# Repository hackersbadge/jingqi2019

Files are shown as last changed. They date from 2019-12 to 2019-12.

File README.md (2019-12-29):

# Hacker's Badge for JD's JingQi 2019, Beijing

- [x] Hardware: WhiteA10n3
- [x] Code: chenhuitao/xwings

* SoC: MTK7688
* 1 x Antenna 
* WiFi Capable
* Breed Bootloader
* 2 Buttons
* 3 x LED

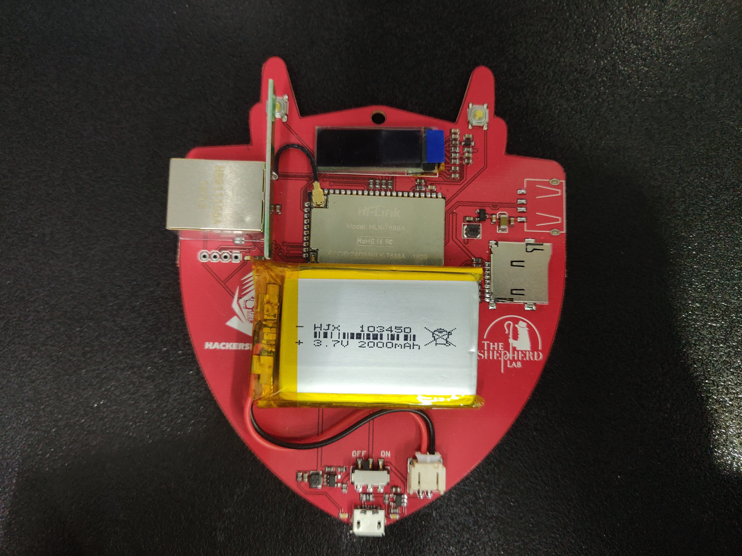
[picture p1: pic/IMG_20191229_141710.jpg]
badge0
      
badge0      
badge0

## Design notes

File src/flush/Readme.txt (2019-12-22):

1. 准备一台linux系统pc机，建议安装ubuntu。
2. 安装python3和curl。
3. 准备一台傻瓜交换机，接入两个网线。
4. 一根网线接入pc机，建议将pc机网络地址设置为192.168.1.100/24。
5. 打开终端，运行python breed_abort.py，此程序将不停在交换机局域网内广播breed abort的指令。
6. 再打开另一个终端，运行while [ true ]; do bash flush.sh; done，此程序会不停的检测breed的web server。
7. 另一根网线接入准备要刷入固件的机器。
8. 电源接入要刷入固件的机器并开启。
9. 观察网络灯是否有闪烁并持续一定时间，闪烁表示正在上传固件。
10. 固件刷入完成后，刷好的机器会自动重启。
11. 此时pc机的flush脚本检测到后会蜂鸣，pc机上的终端也会有提示。
12. 听到蜂鸣后或看到提示后，请在5秒内拔出已经刷机完成的网线，并拔出电源线。
13. 更换新的要刷入的机器，并跳回步骤7进行重复操作。

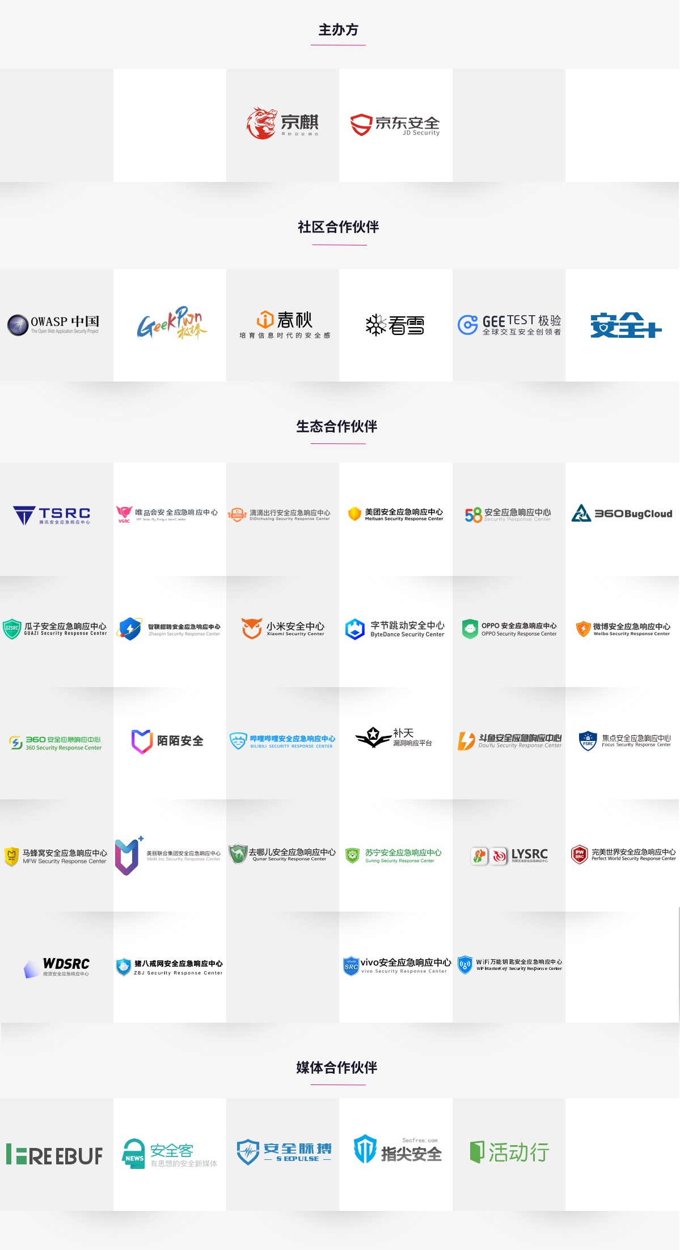
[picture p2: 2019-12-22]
src/package/utils/jd-jingqi/files/www/res/partner-pc.jpeg

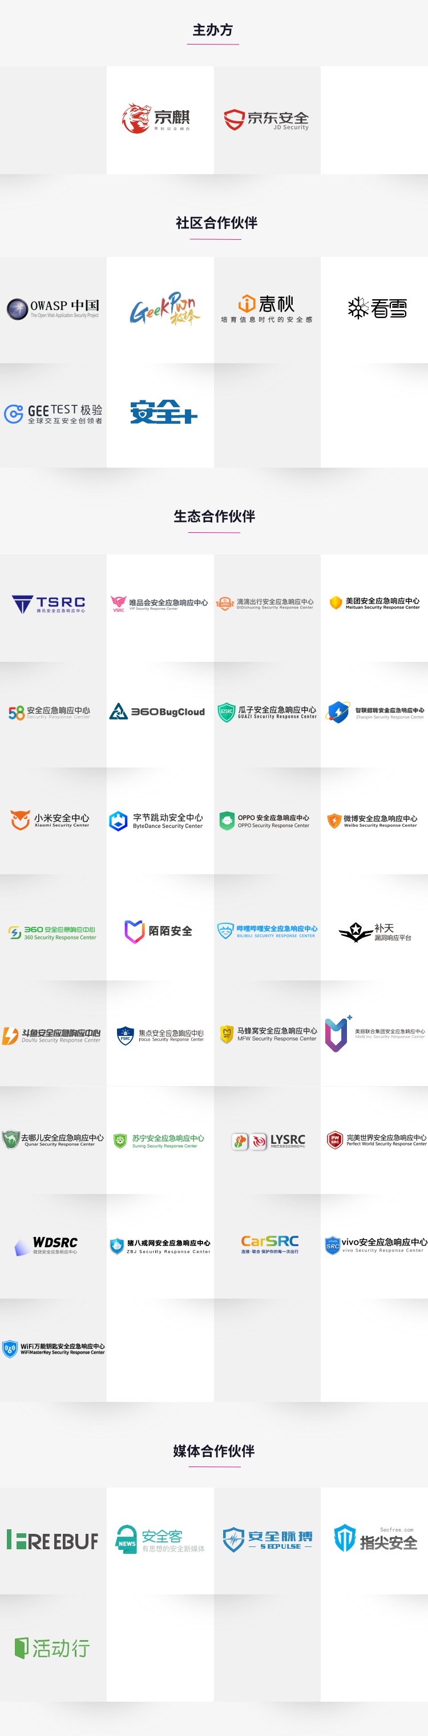
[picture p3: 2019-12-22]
src/package/utils/jd-jingqi/files/www/res/partner-mob.jpeg

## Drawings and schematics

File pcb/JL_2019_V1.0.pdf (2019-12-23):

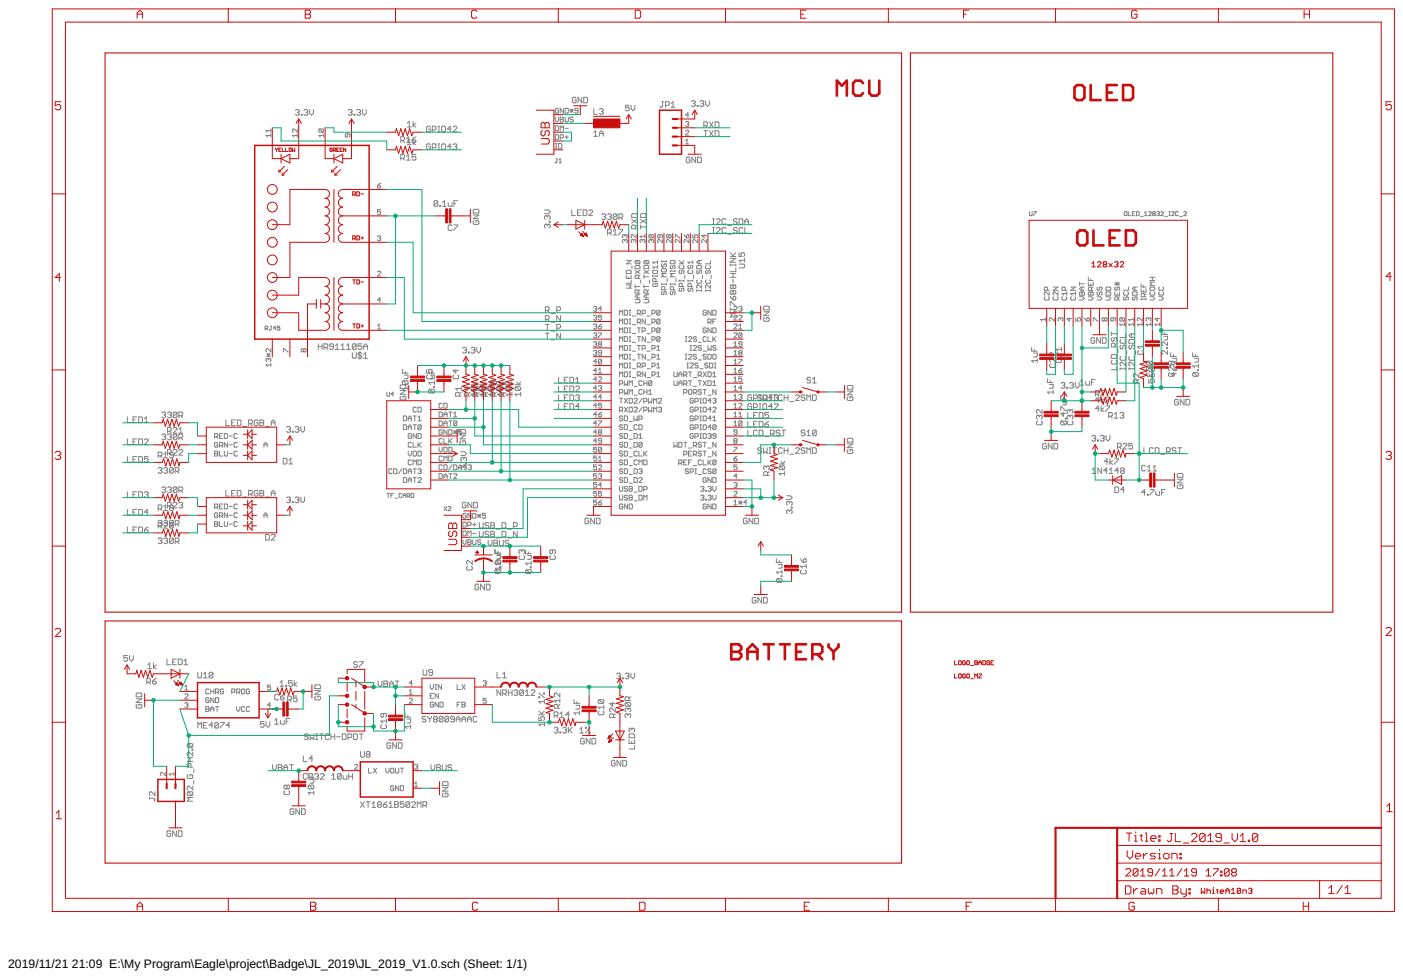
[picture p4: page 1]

2019/11/21 21:09 E:\My Program\Eagle\project\Badge\JL_2019\JL_2019_V1.0.sch (Sheet: 1/1)

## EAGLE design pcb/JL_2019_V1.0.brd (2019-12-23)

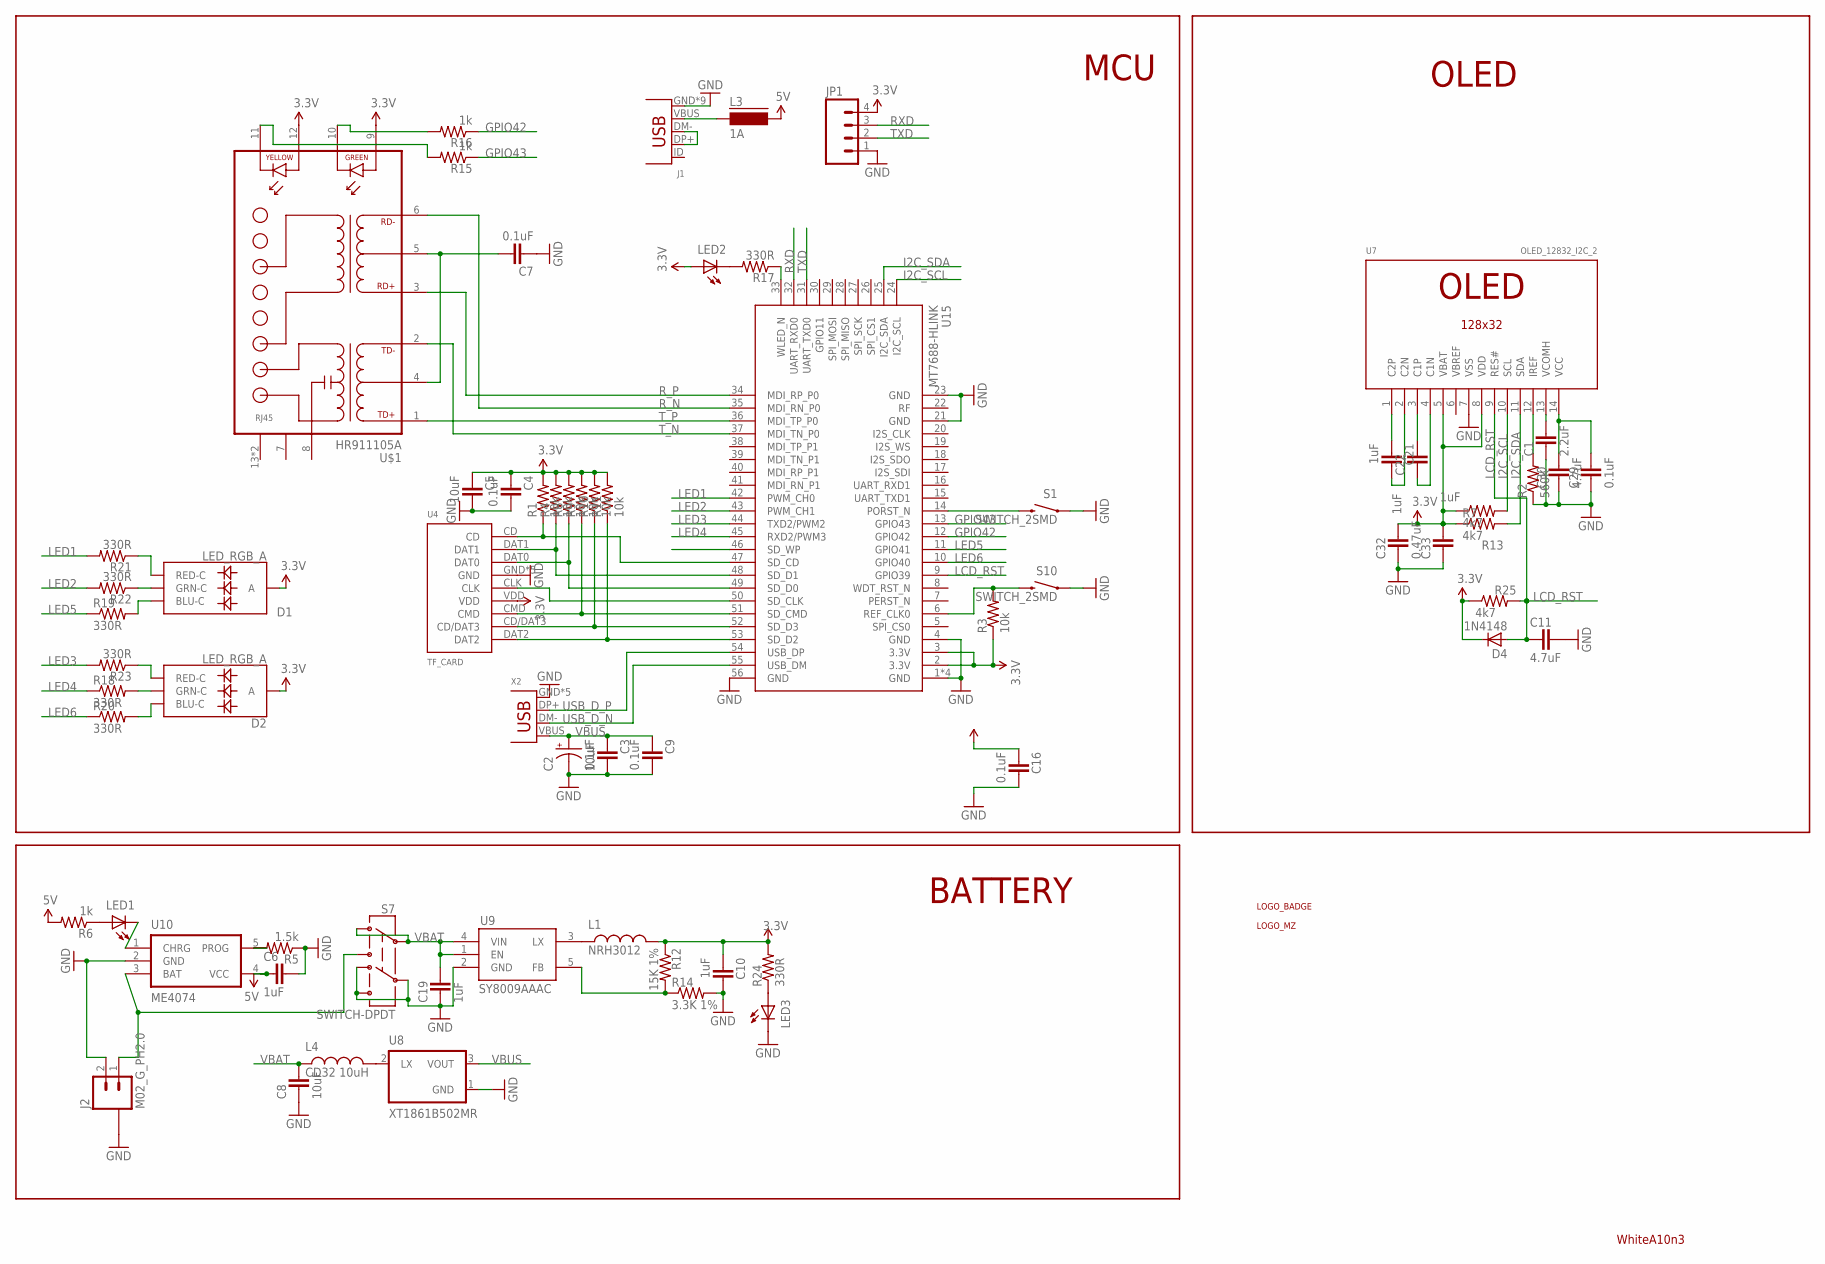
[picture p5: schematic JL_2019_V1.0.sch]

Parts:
C1: 2.2uF; 0603-CAP
C2: 10uF; EIA3216
C3, C4, C7, C9, C16, C29: 0.1uF; 0603-CAP
C5, C8: 10uF; 0603-CAP
C6, C10, C19, C21, C22, C33: 1uF; 0603-CAP
C11, C30: 4.7uF; 0603-CAP
C32: 0.47uF; 0603-CAP
D1, D2: LED_RGB_A; RGB-1615-A
D4: 1N4148; SOD-323F
J1: USB_5_MICRO_4; USB-MICRO-4
J2: M02_G_PH2.0; PH2.0_SMD_2
JP1: M04PTH; 1X04
L1: NRH3012; 1210
L3: 1A; FB805
L4: CD32 10uH; CD32
LED1, LED2, LED3: LED0603; LED-0603
R1, R3, R4, R8, R9, R10, R11: 10k; 0603-RES
R2: 560K; 0603-RES
R5: 1.5k; 0603-RES
R6, R15, R16: 1k; 0603-RES
R7, R13, R25: 4k7; 0603-RES
R12: 15K 1%; 0603-RES
R14: 3.3K 1%; 0603-RES
R17, R18, R19, R20, R21, R22, R23, R24: 330R; 0603-RES
S1, S10: SWITCH_2SMD; TACTILE_SWITCH_SMD
S7: SWITCH-DPDT; MSS22D18
U4: TF_CARD; MICRO-SD-TF
U5: LOGO_BADGE_24.3_20_S
U6: LOGO_MZ_16_14_S
U7: OLED_12832_I2C_2; OLED_12832_0.91_2
U8: XT1861B502MR; SOT23-3
U9: SY8009AAAC; SOT23-5
U10: ME4074; SOT23-5
U15: MT7688-HLINK; MT7688_HLINK
U$1: HR911105A
X2: USB_4_4; USB-A-4

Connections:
3.3V: C4.2, C5.2, C10.2, C16.2, C32.1, C33.1, D1.A, D2.A, D4.C, JP1.4, L1.2, LED2.A, R1.2, R3.1, R4.2, R7.1, R8.2, R9.2, R10.2, R11.2, R12.1, R13.1, R24.2, R25.1, U4.VDD, U7.5 (VBAT), U7.8 (VDD), U15.2 (3.3V), U15.3 (3.3V), U$1.9, U$1.12
5V: C6.2, L3.1, R6.2, U10.4 (VCC)
GND: C1.2, C2.C (-), C3.1, C4.1, C5.1, C6.1, C7.2, C8.2, C9.1, C10.1, C11.1, C16.1, C19.2, C29.2, C30.2, C32.2, C33.2, J1.GND, J1.MT1 (GND), J1.MT2 (GND), J1.MT5 (GND), J1.MT6 (GND), J1.MT7 (GND), J1.MT8 (GND), J1.MT9 (GND), J1.MT10 (GND), J2.2, J2.G1 (G), J2.G2 (G), JP1.1, LED3.C, R2.1, R5.1, R14.2, S1.1, S7.4, S7.5, S7.6, S10.1, U4.GND, U4.GND1 (GND), U4.GND2 (GND), U4.GND3 (GND), U4.GND4 (GND), U7.7 (VSS), U8.1 (GND), U9.2 (GND), U10.2 (GND), U15.1 (GND), U15.4 (GND), U15.21 (GND), U15.23 (GND), U15.56 (GND), U15.PAD (GND), U15.PAD1 (GND), U15.PAD2 (GND), X2.GND, X2.P$5 (GND), X2.P$6 (GND), X2.P$7 (GND), X2.P$8 (GND)
GPIO42: R16.1, U15.12 (GPIO42)
GPIO43: R15.1, U15.13 (GPIO43)
I2C_SCL: R13.2, U7.10 (SCL), U15.24 (I2C_SCL)
I2C_SDA: R7.2, U7.11 (SDA), U15.25 (I2C_SDA)
LCD_RST: C11.2, D4.A, R25.2, U7.9 (RES#), U15.9 (GPIO39)
LED1: R21.2, U15.42 (PWM_CH0)
LED2: R22.2, U15.43 (PWM_CH1)
LED3: R23.2, U15.44 (TXD2/PWM2)
LED4: R18.1, U15.45 (RXD2/PWM3)
LED5: R19.1, U15.11 (GPIO41)
LED6: R20.1, U15.10 (GPIO40)
unnamed: L4.P$2 (2), U8.2 (LX)
unnamed: LED3.A, R24.1
unnamed: J2.1, S7.3, U10.3 (BAT)
unnamed: C1.1, U7.13 (VCOMH)
unnamed: D1.R (RED-C), R21.1
unnamed: D1.G (GRN-C), R22.1
unnamed: R5.2, U10.5 (PROG)
unnamed: R11.1, U4.DAT2, U15.53 (SD_D2)
unnamed: R10.1, U4.CD/DAT3, U15.52 (SD_D3)
unnamed: LED1.A, R6.1
unnamed: LED1.C, U10.1 (CHRG)
unnamed: J1.VBUS, L3.2
unnamed: R9.1, U4.CMD, U15.51 (SD_CMD)
unnamed: U4.CLK, U15.50 (SD_CLK)
unnamed: R1.1, U4.CD, U15.47 (SD_CD)
unnamed: C21.2, U7.1 (C2P)
unnamed: C21.1, U7.2 (C2N)
unnamed: C22.1, U7.3 (C1P)
unnamed: C22.2, U7.4 (C1N)
unnamed: R8.1, U4.DAT0, U15.49 (SD_D0)
unnamed: C29.1, C30.1, U7.14 (VCC)
unnamed: R2.2, U7.12 (IREF)
unnamed: R4.1, U4.DAT1, U15.48 (SD_D1)
unnamed: L1.1, U9.3 (LX)
unnamed: R12.2, R14.1, U9.5 (FB)
unnamed: D1.B (BLU-C), R19.2
unnamed: D2.R (RED-C), R23.1
unnamed: D2.G (GRN-C), R18.2
unnamed: C7.1, U$1.4, U$1.5
unnamed: R15.2, U$1.11
unnamed: R16.2, U$1.10
unnamed: LED2.C, R17.2
unnamed: R17.1, U15.33 (WLED_N)
unnamed: D2.B (BLU-C), R20.2
unnamed: J1.DM- (D-), J1.DP+ (D+)
RST: S1.3 (2), U15.14 (PORST_N)
RST2: R3.2, S10.3 (2), U15.6 (REF_CLK0)
RXD: JP1.3, U15.32 (UART_RXD0)
R_N: U15.35 (MDI_RN_P0), U$1.6
R_P: U15.34 (MDI_RP_P0), U$1.3
TXD: JP1.2, U15.31 (UART_TXD0)
T_N: U15.37 (MDI_TN_P0), U$1.2
T_P: U15.36 (MDI_TP_P0), U$1.1
USB_D_N: U15.55 (USB_DM), X2.DM-
USB_D_P: U15.54 (USB_DP), X2.DP+
VBAT: C8.1, C19.1, L4.P$1 (1), S7.1, S7.2, U9.1 (EN), U9.4 (VIN)
VBUS: C2.A (+), C3.2, C9.2, U8.3 (VOUT), X2.VBUS

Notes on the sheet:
MCU
BATTERY
WhiteA10n3
OLED

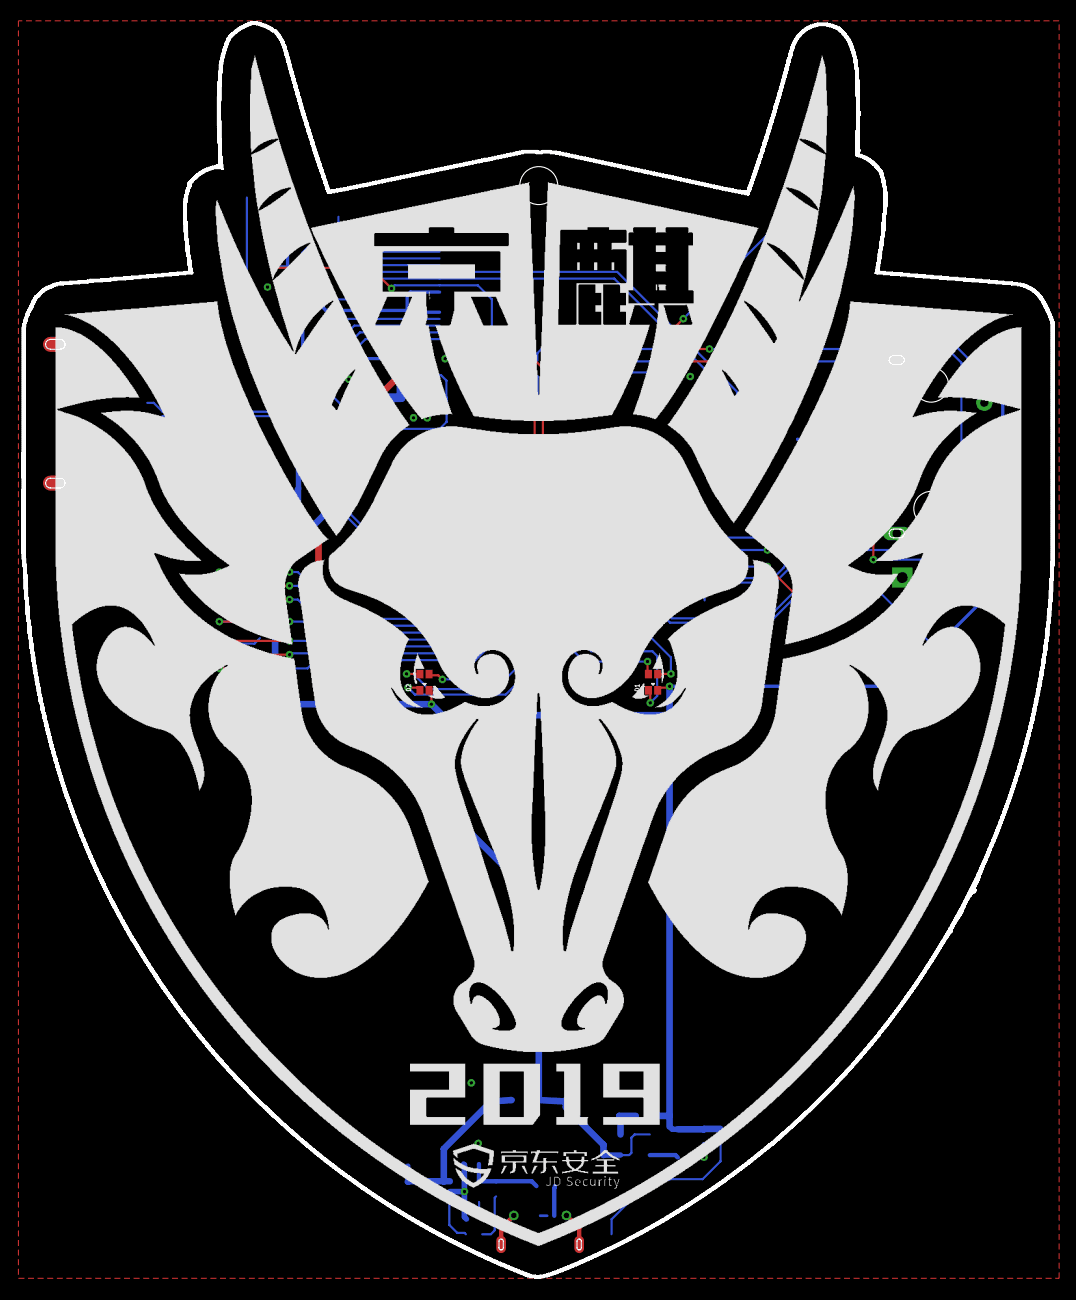
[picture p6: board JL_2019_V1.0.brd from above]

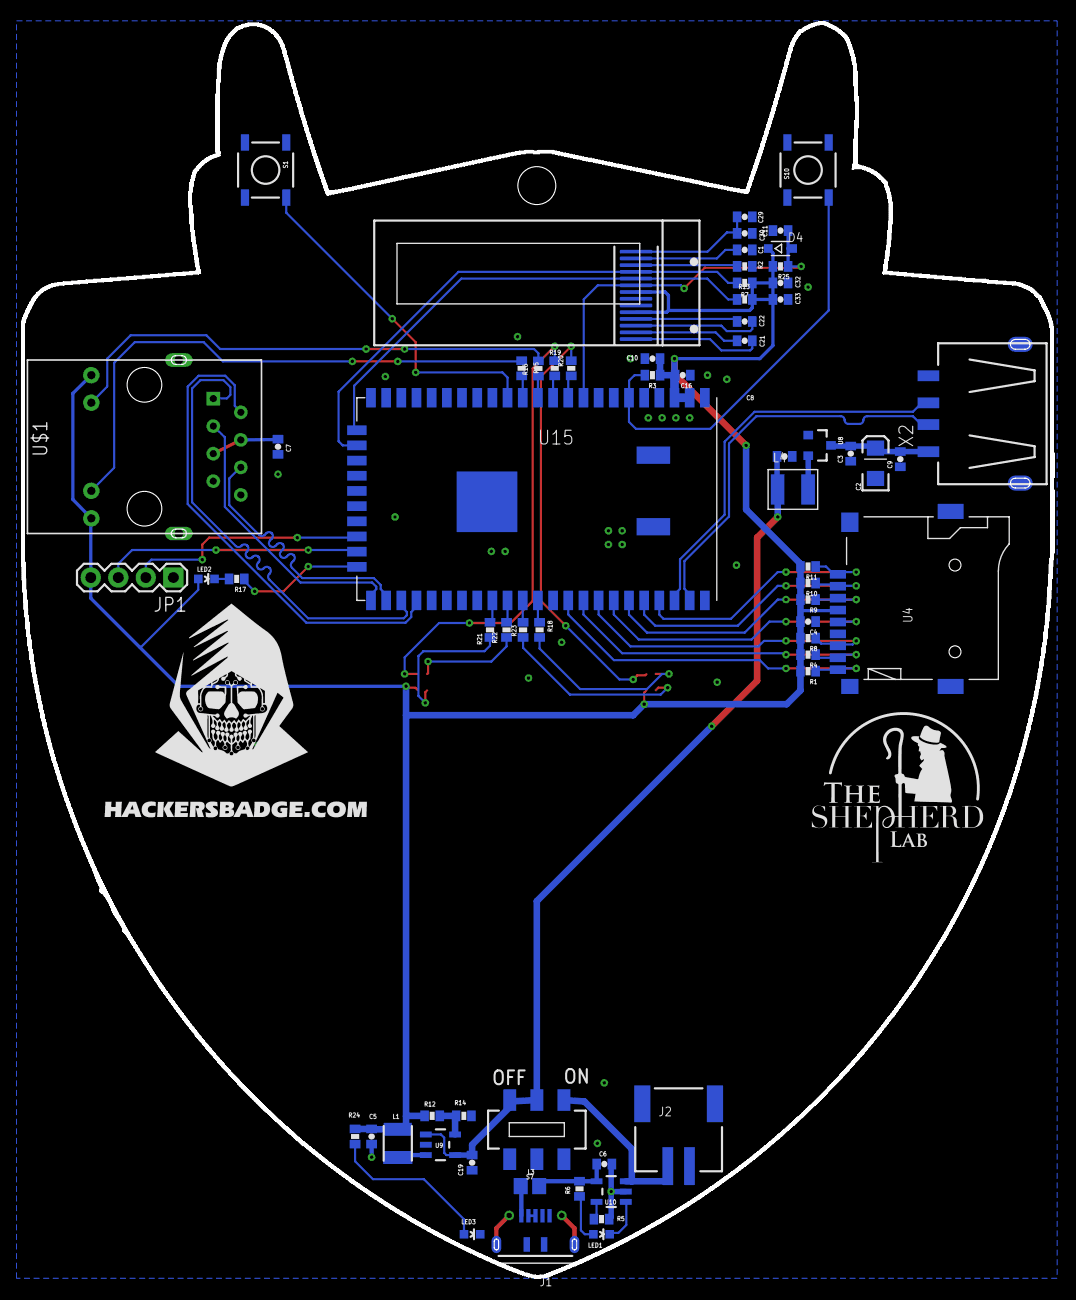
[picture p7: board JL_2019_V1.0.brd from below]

Board: 2 copper layers, 95.2 x 115.9 mm, 69 parts (67 on the bottom side), 61 nets.

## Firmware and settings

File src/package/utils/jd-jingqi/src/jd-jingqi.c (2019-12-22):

/*
 * Copyright (c) 2015, Vladimir Komendantskiy
 * MIT License
 *
 * SSD1306 demo of block and font drawing.
 */

//
// fixed for OrangePiZero by HypHop
//

#include <errno.h>
#include <string.h>
#include <stdio.h>
#include <stdlib.h>
#include <time.h>
#include <stdint.h>
#include <unistd.h>
#include <sys/types.h>
#include <sys/stat.h>

#include <pthread.h>

#include "oled.h"
#include "font.h"

#define I2C_DEV     "/dev/i2c-0"
#define ACTIVE_SH   "/etc/shepherd-active.sh"

static void *blink_the_led(void * arg)
{
    int i, j, k, count;
    int led[6] = {42, 41, 40, 21, 19, 20};
    char cmd[64];

#if 1
    /* init the sysfs gpio */
    for (i = 0; i < 6; i++) {
        snprintf(cmd, sizeof(cmd), "echo %d > /sys/class/gpio/export", led[i]);
        system(cmd);
        usleep(1000);
        snprintf(cmd, sizeof(cmd), "echo out > /sys/class/gpio/gpio%d/direction", led[i]);
        system(cmd);
        usleep(1000);
    }
#endif

    count = 2019 * 4;
    for (i = 0; i < count; i++) {
        j = i % 6;
        k = (i + 1) % 6;
        snprintf(cmd, sizeof(cmd), "echo 1 > /sys/class/gpio/gpio%d/value", led[j]);
        system(cmd);
        snprintf(cmd, sizeof(cmd), "echo 0 > /sys/class/gpio/gpio%d/value", led[k]);
        system(cmd);
        usleep(20000);
        snprintf(cmd, sizeof(cmd), "echo 0 > /sys/class/gpio/gpio%d/value", led[j]);
        system(cmd);
        snprintf(cmd, sizeof(cmd), "echo 1 > /sys/class/gpio/gpio%d/value", led[k]);
        system(cmd);
        usleep(20000);
    }

    /* off them all */
    for (i = 0; i < 6; i++) {
        snprintf(cmd, sizeof(cmd), "echo 0 > /sys/class/gpio/gpio%d/value", led[i]);
        system(cmd);
    }

    return NULL;
}

static int uci_get(const char *key, char *value, int value_len)
{
    int ret;
    FILE *fp;
    char cmd[64];

    snprintf(cmd, sizeof(cmd), "uci get %s", key);
    fp = popen(cmd, "r");
    if (fp == NULL) {
        return -1;
    }
    fgets(value, value_len, fp);
    ret = strlen(value);
    if (ret == 0) {
        return -2;
    } else {
        /* remove tail LF */
        value[ret - 1] = 0;
    }
    pclose(fp);

    return 0;
}

int main(int argc, char **argv) {
	struct display_info disp;
    int ret;
    char ssid[16];
    char key[16];
    struct stat st;
    FILE *fp;
    char buf[64];
    pthread_t pt;
    void *thread_ret;

	memset(&disp, 0, sizeof(disp));
	disp.address = OLED_I2C_ADDR;
	disp.font = font2;

    for (;;) {
        ret = oled_open(&disp, I2C_DEV);
        if (ret < 0) {
            fprintf(stderr, "oled open i2c device error.\n");
            continue;
            sleep(1);
        }
        ret = oled_init(&disp);
        if (ret < 0) {
            fprintf(stderr, "oled init error.\n");
            oled_close(&disp);
            sleep(1);
            continue;
        } else {
            break;
        }
    }

    /* check the flag */
    ret = stat(ACTIVE_SH, &st);
    if (ret == 0) {
        /* show the default string */
        disp.font = font2;
        oled_putstrto(&disp, 8, 4, " JD-JingQi-2019");
        oled_putstrto(&disp, 8, 20, "    - Beijing    ");
        oled_send_buffer(&disp);
        /* up the wifi dev */
        system("ifconfig wlan0 up");
        /* wait active signal */
        for(;;) {
            printf("scan the wifi...\n");
            /* scan the wifi shepherd-lab */
            fp = popen("iw wlan0 scan | grep 'SSID: shepherd-lab' | wc -l", "r");
            if (fp == NULL) {
                sleep(1);
                continue;
            } else {
                fgets(buf, sizeof(buf), fp);
                pclose(fp);
                ret = atoi(buf);
                if (ret != 0) {
                    break;
                }
            }
            sleep(1);
        }
        /* actived. set the flag and blink led light */
        pthread_create(&pt, NULL, blink_the_led, NULL);
        system(ACTIVE_SH);
    }
    /* else show ssid and key */
    memset(ssid, 0, sizeof(ssid));
    memset(key, 0, sizeof(key));
    for(;;) {
        ret = uci_get("wireless.default_radio0.ssid", ssid, sizeof(ssid));
        if (ret) {
            sleep(1);
            continue;
        }
        ret = uci_get("wireless.default_radio0.key", key, sizeof(key));
        if (ret) {
            sleep(1);
            continue;
        }
        break;
    }
    printf("get wireless ssid[%s], key[%s].\n", ssid, key);

    disp.font = font2;
    oled_putstrto(&disp, 4, 4, "SSID: ");
    oled_putstrto(&disp, 4 + 36, 4, ssid);
    oled_putstrto(&disp, 4, 20, "KEY:  ");
    oled_putstrto(&disp, 4 + 36, 20, key);
    oled_send_buffer(&disp);

    pthread_join(pt, &thread_ret);

	return 0;
}

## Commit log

2019-12-23 pending pcb
2019-12-23 upload pcb
    [JL_2019_V1.0.brd, JL_2019_V1.0.sch]

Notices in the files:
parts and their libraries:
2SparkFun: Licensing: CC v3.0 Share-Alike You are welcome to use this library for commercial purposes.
